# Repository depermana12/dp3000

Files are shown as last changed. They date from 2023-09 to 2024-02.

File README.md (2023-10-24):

# DP3000 Macropad
dp3000 macropad

dp3000 is a simple yet elegant macropad, integrated ATmega32u4 chip. I created this dev board named dp3000, the first and second letters are my initials and the three digit numbers are just random numbers like i love u 3000.

DP3000 Macropad
# Features
+ 2x4 (8 keys)
+ dual rotary encoder
+ oled display (support 128x32 or 128x64)
+ hot-swap socket (support mx style or kailh choc low profile)
+ mx style or low profile choc v1, v2* switch
    * *for choc v2 u need to file the center hole in the pcb, don't file pass the white circle line
+ RGB light underglow or RGB matrix
+ support QMK, VIA, VIAL
+ basic stacked acrylic case

# Gallery

dp3000 macropad dp3000 macropad dp3000 macropad
dp3000 macropad dp3000 macropad dp3000 macropad dp3000 macropad 
dp3000 macropad dp3000 macropad

# Getting started

dp3000 have 2 different types of firmware, QMK and VIA. Each firwmare have 2 version.
I recommend using VIA, it's user friendly, and easy to customize.

* rev1 version support `rgb_matrix`
* rev2 version support `rgblight` underglow
* (unofficial) rev3 version support both `rgb_matrix` and `rgblight` (hardware modification needed!)

1. choose your preferred firmware
2. flash the firmware
3. customize your keymap using VIA
4. profit?

# Default keymap


both firmware QMK and VIA come with above default keymap. However, it is important to note that the purpose of this board is primarily to serve as a customizable and programmable for macros.

so, the keymap configuration is intended to be personalized according to the user's specific needs and preferences. 
feel free to assign different keycodes or commands to each key, tailoring the macropad to your own workflow and requirements.

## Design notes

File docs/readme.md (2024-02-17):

# Introduction dp3000

dp3000 macropad  didesain full feature dan compact, tidak terlalu banyak switch

sekaligus jadi dev board

untuk nyoba fitur hardware dan firmware. Itu kenapa dp3000 didesain punya beberapa opsi

opsi lighting underglow atau rgbmatrix

opsi hot-swap socket

opsi ukuran modul oled

opsi firmware via, vial

## Embedded ATmega32u4

Dilihat lebih detil, dp3000 tidak memakai shield promicro... tapi ic promicro dipasang langsung di pcb dp3000

jadi lebih slim dan seksi

minimalis, elegan

alias manfaatin promicro yang port micro usbnya copot (type c pride)

biar ga mubazir

sayang 70rban

## Dev board

Untuk yang suka ngoprek firmware, atau lagi sambil belajar C, ini macropad cocok banget.

source code qmk terlampir

compiled .hex yang tinggal flash jg ada

firmware rev1 dan rev 2 sudah merged dengan repo qmk dan via

jadi sudah auto-detect untuk digunakkan langsung lewat web https://usevia.app

pcb juga mendukung untuk dimodif, hotswap socket bisa diganti ke varian choc socket

Oled bisa diganti ke ukuran 128x64

`rgb_matrix` bisa digabung `rgblight` underglow, dengan menyolder kabel jumper (tutorialnya menyusul)

icsp header

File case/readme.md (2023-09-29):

# Case akrilik dp3000

case ini sudah siap dipotong laser, untuk beli dan jasa potong akrilik saya rekomendasikan di [tokopedia.com/3dinnova](https://www.tokopedia.com/3dinnova) total harga sekitar Rp 30.000 untuk 3mm bening

1. Gunakan file 3mm case full jika keseluruhan 6 lapis akrilik ingin menggunakan warna akrilik yang sama
2. Jika ingin lapis akrilik bawah dan atas menggunakan warna berbeda, gunakan file bottom 3mm.dxf dan top 3mm.dxf

    - rekomendasi akrilik bawah menggunakan warna bening satin dengan kode 000M, karena frosted warna ini cocok untuk diffused led underglow
    - akrilik atas gunakan warna yang tembus oled, bisa warna bening, atau clear black.

contoh dari 3mm case full



contoh bottom 3mm



contoh mid 3mm



contoh top 3mm



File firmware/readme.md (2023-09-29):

# Compiled firmware

The compiled firmware is ready to flash, and you can download it from [here](https://drive.google.com/drive/folders/1hYmq0JSfdpY_xRYRoUmOEOPrWqblNjE2?usp=drive_link).

# Raw Firmware

* Rev. 1 Support RGB matrix
* Rev. 2 Support RGB light (underglow)

Make example for this keyboard (after setting up your build environment):

    make dp3000/rev1:default
    make dp3000/rev2:default
    make dp3000/rev1:via
    make dp3000/rev2:via

Flashing example for this keyboard:

    make dp3000/rev1:default:flash
    make dp3000/rev2:default:flash
    make dp3000/rev1:via:flash
    make dp3000/rev2:via:flash

See the [build environment setup](https://docs.qmk.fm/#/getting_started_build_tools) and the [make instructions](https://docs.qmk.fm/#/getting_started_make_guide) for more information. Brand new to QMK? Start with our [Complete Newbs Guide](https://docs.qmk.fm/#/newbs).

## Bootloader

Enter the bootloader in 3 ways:

* Bootmagic reset: Hold down the key at (0,0) in the matrix (left rotary encoder push switch) and plug in the keyboard
* Physical reset button: Briefly press reset button twice, located in front of the first rotary encoder (left rotary encoder)
* Keycode in layout: Press the key mapped to QK_BOOT if it is available

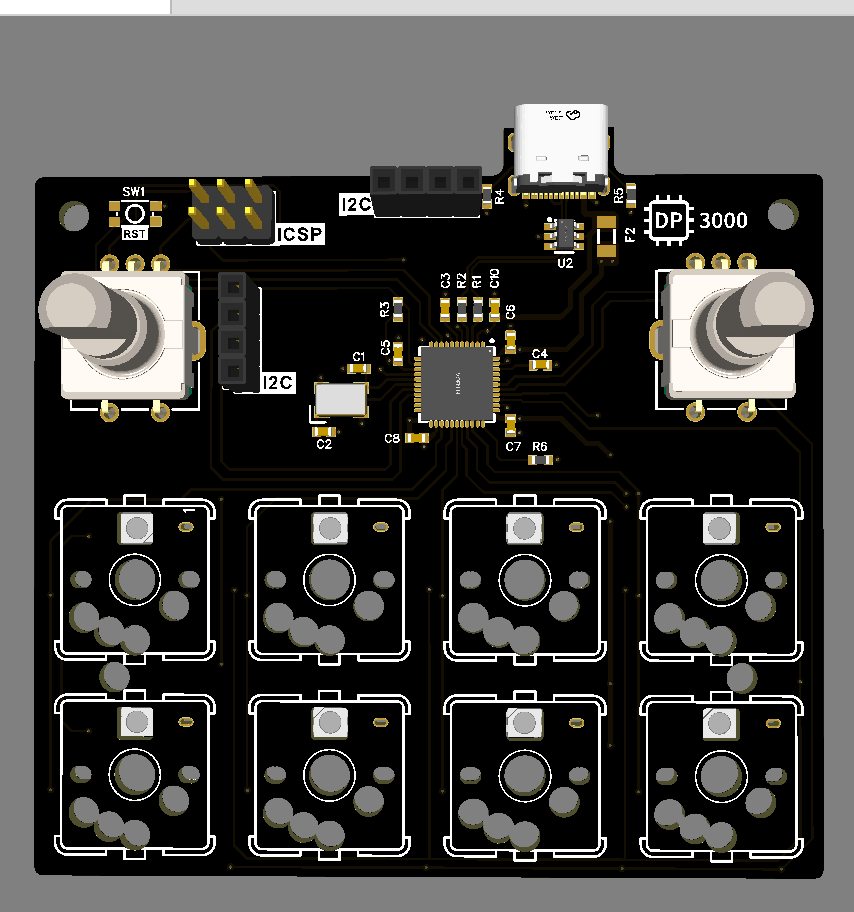
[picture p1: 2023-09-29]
gerber/front.png

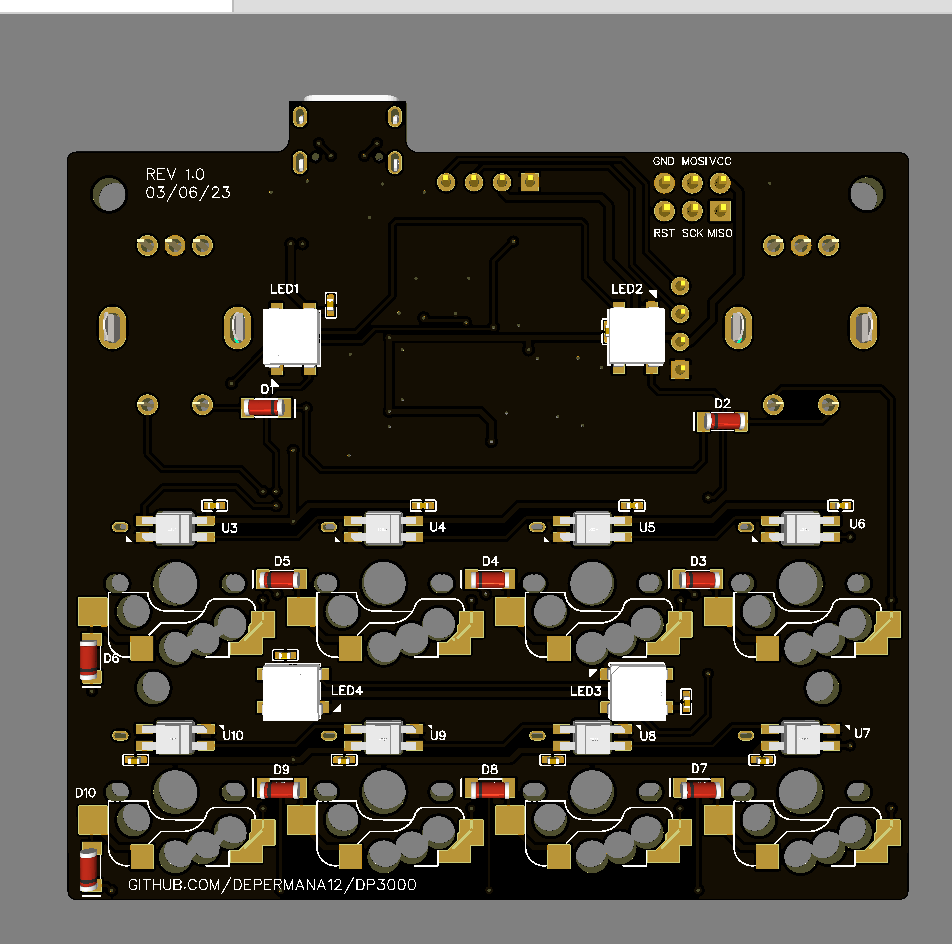
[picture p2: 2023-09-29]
gerber/back.png

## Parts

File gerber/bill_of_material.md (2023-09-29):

|ID |Part name |Origin |Package |Qty|
|---|---|---|---|---|
|1  |DISPLAY-OLED-128X32  |1,2 |I2C |2  |
|2  |22pF |C1,C2 |C0603 |2  |
|3  |1uF |C3 |C0603 |1  |
|4  |0.1uF |C4 |C0603 |1  |
|5  |0.1u |C5,C6,C7,C8 |C0603 |4  |
|6  |10uF |C10 |C0603 |1  |
|7  |0.1u |C11,C12,C13,C14,C15,C16,C17,C18,C19,C20,C21,C22|C0402 |12 |
|8  |1N4148(SMD) |D1,D2,D3,D4,D5,D6,D7,D8,D9,D10 |1N4148 SOD 123 |10 |
|9  |500mA ptc fuse |F2 |PTC-1206 |1  |
|10 |Header-Male-2.54_2x3 |J1 |2.54 pitch |1  |
|11 |5050-WS2812B |LED1,LED2,LED3,LED4 |WS2812B 5050 |4  |
|12 |5.1k |R1,R2,R4,R5 |R0603 |4  |
|13 |10k |R3,R6 |R0603 |2  |
|14 |16MHz |R7 |CRYSTAL-SMD_4P-L5.0-W3.2 |1  |
|15 |TS-1185A-020E |SW1 |SW-SMD_4P-L3.5-W3.0-LS4.6-TL |1  |
|16 |PEC11R-4015F-S0024 |SW2,SW35 |SW-TH_PEC11R-4XXXF-SXXXX |2  |
|17 |KAILH MX & CHOC |SW12,SW13,SW14,SW15,SW16,SW17,SW18,SW19 |SWITCH SOCKET MX & CHOC |8  |
|18 |ATMEGA32U4-MU |U1 |QFN-44 |1  |
|19 |SRV05 |U2 |SOT-23-6 |1  |
|20 |SK6812 MINI-E |U3,U4,U5,U6,U7,U8,U9,U10 |SK6812 MINI-E |8  |
|21 |KH-TYPE-C-16P |USB1 |USB TYPE C 16P |1  |

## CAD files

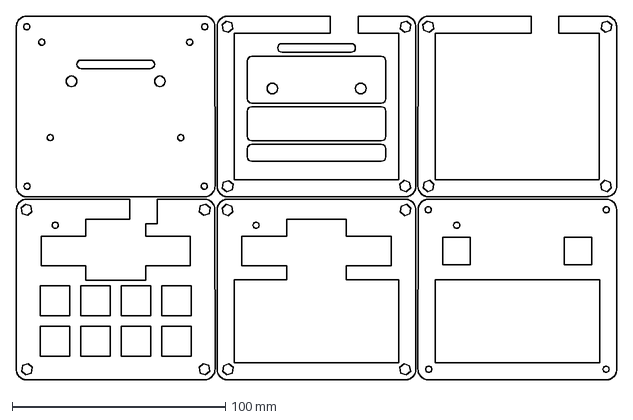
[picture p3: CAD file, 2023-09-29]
case/3mm case full.dxf
281.7 x 170.7 mm

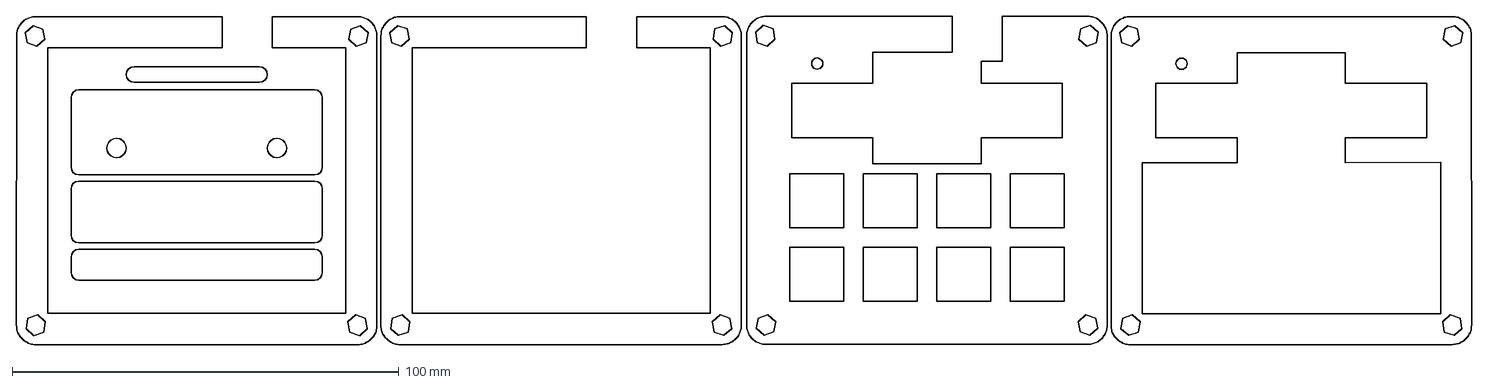
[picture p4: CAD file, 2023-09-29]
case/mid 3mm.dxf
376.2 x 84.9 mm

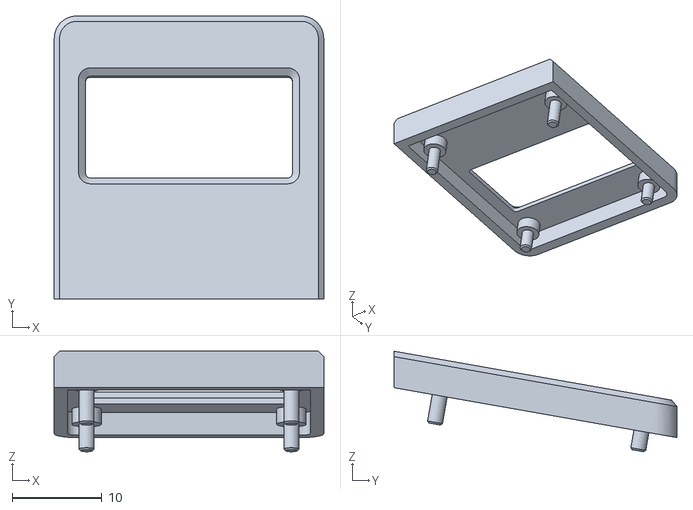
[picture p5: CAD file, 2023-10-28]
case/oled_case/oled_case_front.stl
30.0 x 31.5 x 11.2

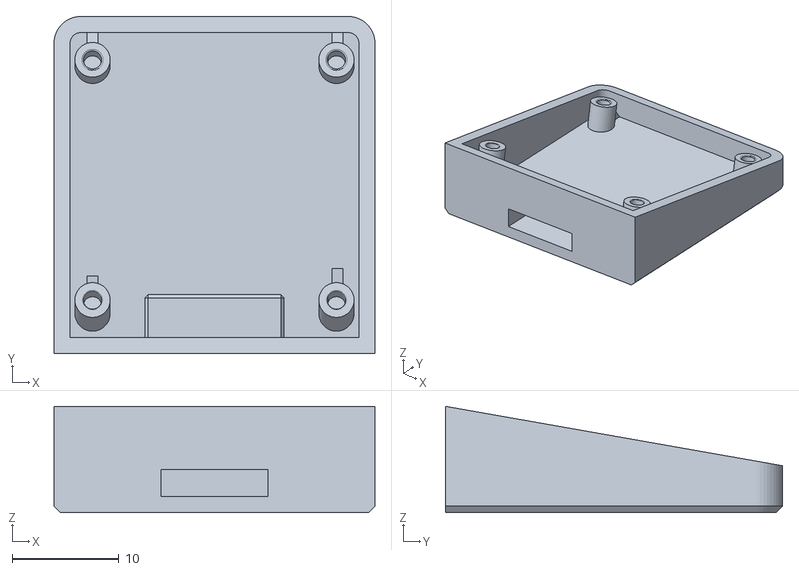
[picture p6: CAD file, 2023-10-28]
case/oled_case/oled_case_back.stl
30.0 x 31.5 x 9.94

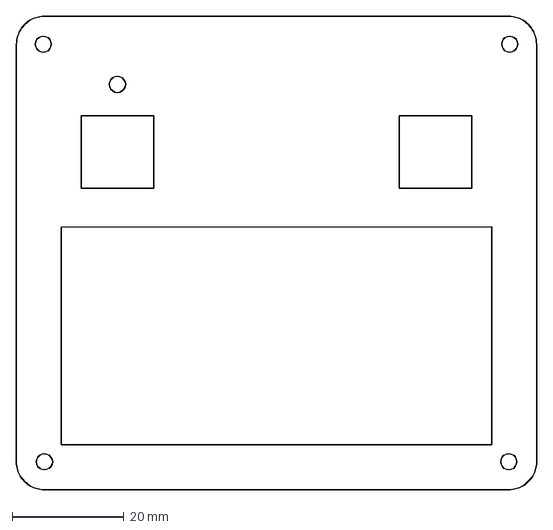
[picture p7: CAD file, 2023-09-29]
case/top 3mm.dxf
93.2 x 84.8 mm

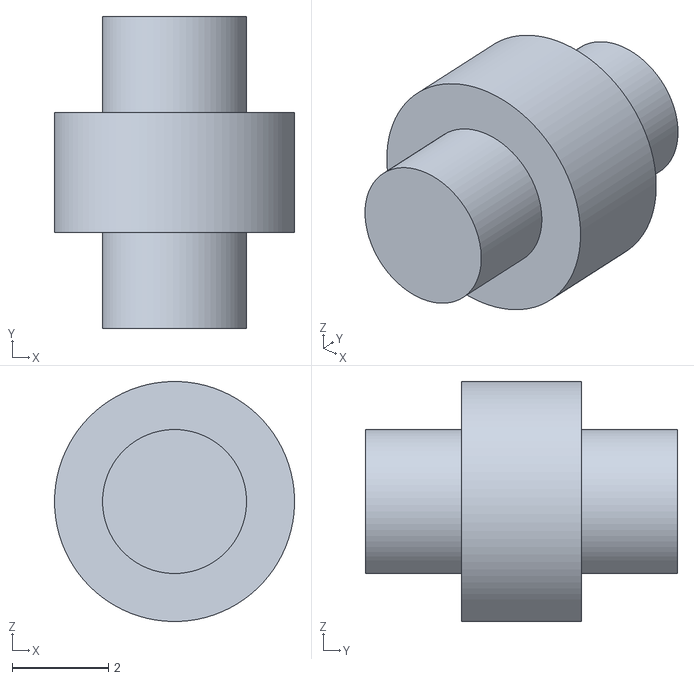
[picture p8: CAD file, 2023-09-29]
case/Mounting_standoff.stl
5.00 x 6.50 x 5.00

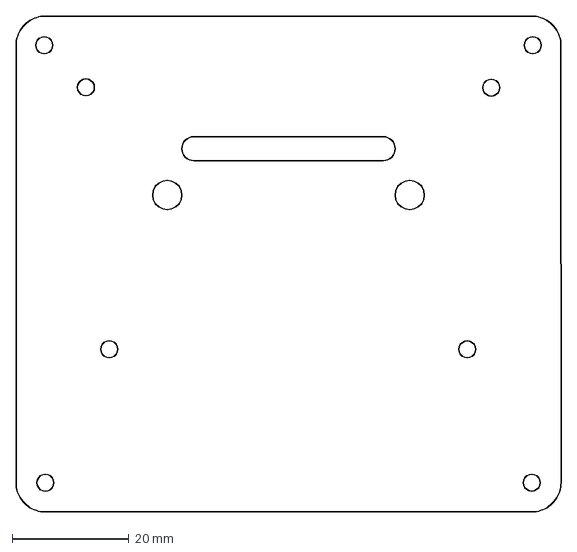
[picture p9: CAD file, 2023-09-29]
case/bottom 3mm.dxf
93.2 x 84.8 mm

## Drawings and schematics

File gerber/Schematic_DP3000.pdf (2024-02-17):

## USB INTERFACE

ICSP | MICROCONTROLLER

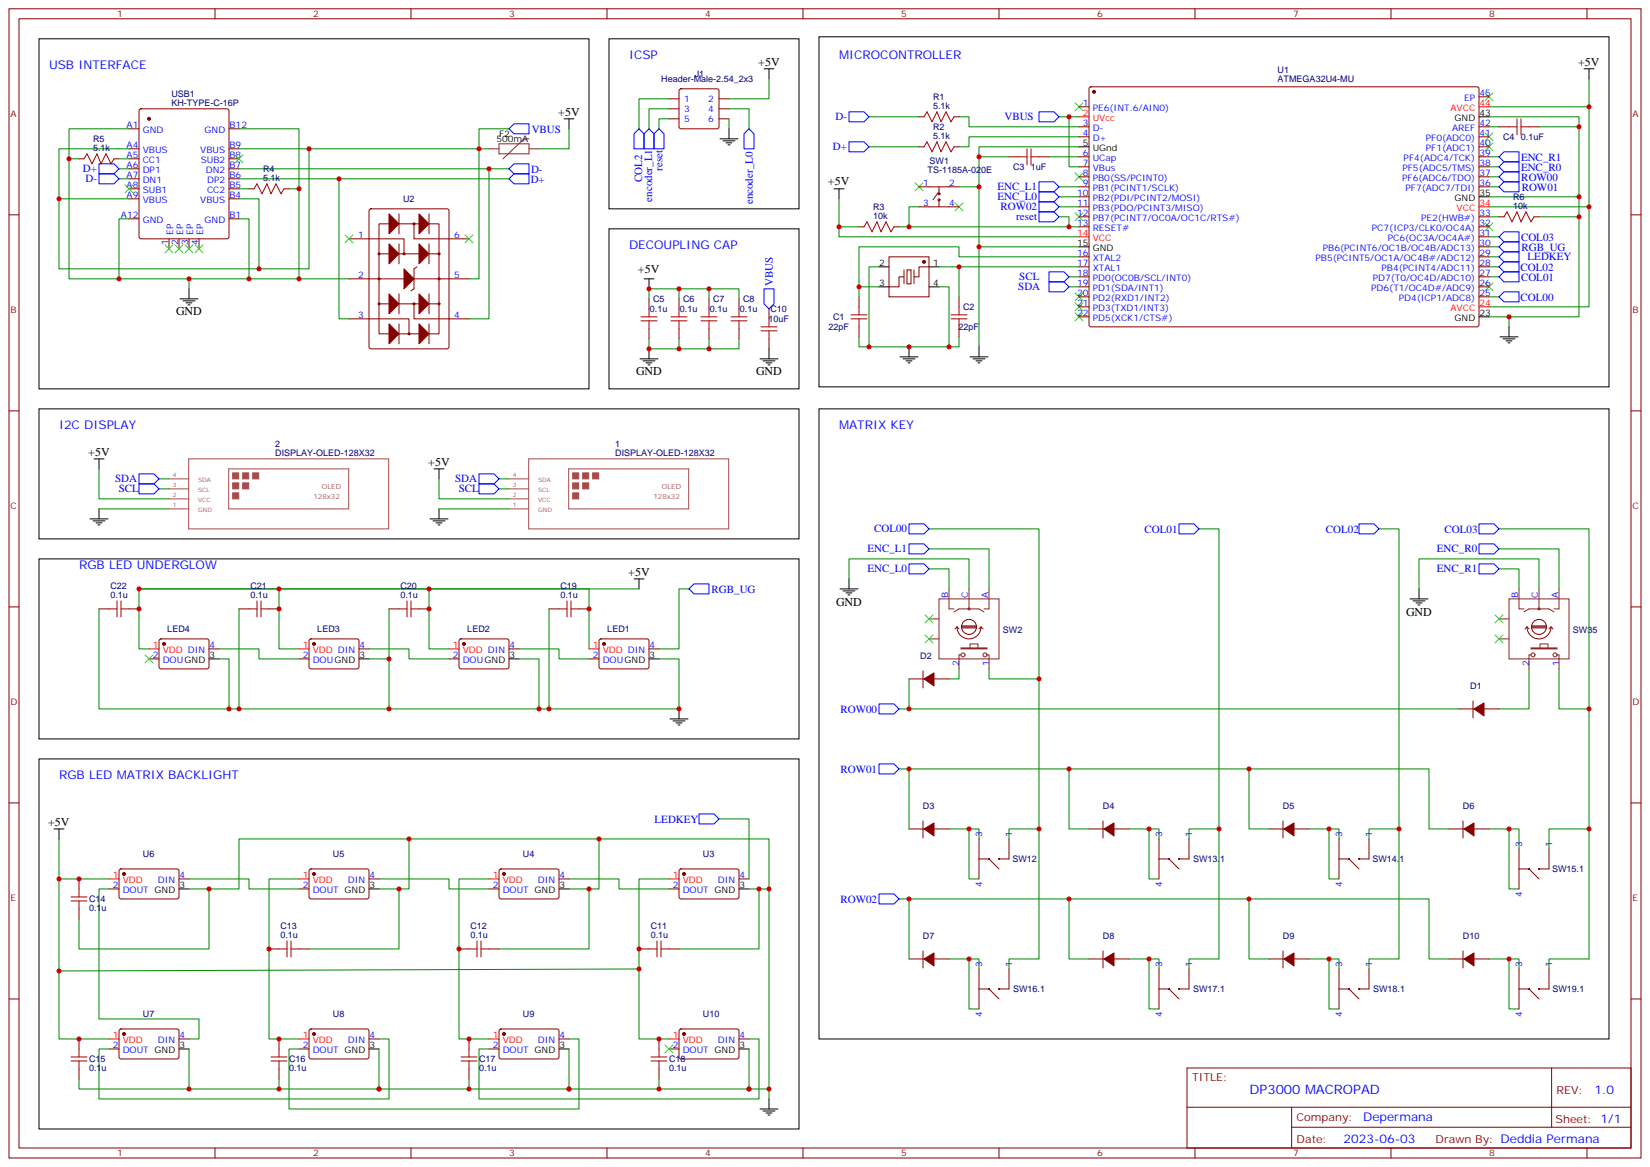
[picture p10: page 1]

RGB LED MATRIX BACKLIGHT

Drawn By: Deddia Permana

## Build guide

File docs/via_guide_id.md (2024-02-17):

# Panduan menggunakan VIA
Normal QMK firmware untuk mapping keymap membutuhkan modifikasi kode keymap.c di dalam build environment atau qmk configurator yang dicompile untuk menghasilkan file hex yang akan diflash. Cara ini cukup sulit dan tidak efisien untuk untuk beberapa pengguna.

VIA menutup gap tersebut dengan memberikan kemudahan pengguna untuk mengubah keymap tanpa harus flash firmware. Gui untuk mengatur lighting mode, speed, dan brightness. Programming macros.

Via adalah fitur yang berdiri dengan pondasi qmk firmware

## via configurator
VIA punya dua tipe configurator, web app dan desktop app. Panduan ini menggunakan web app agar lebih sederhana. Untuk desktop app sama saja seperti web app. 

Pastikan terkoneksi internet, dan gunakan browser yang mendukung web hid seperti chrome, safari, opera, edge.

1. buka alamat [VIA configurator](https://usevia.app/)
2. klik authorize device, pilih dp3000 lalu klik connect
   
dp3000 macropad

1. Tampilan setelah terkoneksi

dp3000 macropad

4. Pada tampilan di atas, pengguna dapat mengubah langsung setiap key di setiap layer. Jangan lupa juga untuk menambahkan key untuk berpindah layer

## Mapping rotary encoder

pengguna dapat melakukan mapping fungsi rotary encoder di setiap layer berbeda.

1. klik lingkaran rotary encoder
2. masukan fungsi untuk searah jarum jam, berlawan jarum jam, dan tombol rotary.

daftar fungsi [keycode qmk](https://docs.qmk.fm/#/keycodes)

dp3000 macropad

## Setting layer switching

Imgur

Secara bawaan dp3000 macropad mendukung 4 layer, dimulai dari 0 sebagai base default layer

Setting pindah layer dapat dilakukan di via dengan mengatur keymap dengan `LAYERS` keycode yang disediakan diatas.

Agar sederhana, pengguna dapat menggunakan basic keycode:

1. ``MO(nomor_layer)`` Momentary Open berfungsi untuk mengaktifkan layer sementara, saat ditekan akan mengaktifkan layer, saat dilepas akan kembali ke layer sebelumnya
2. ``TO(nomor_layer)`` Turn On berfungsi untuk mengaktifkan layer

Fungsi lengkap dapat dilihat di [QMK docs layer switching](https://docs.qmk.fm/#/feature_layers?id=switching-and-toggling-layers)

dp3000 macropad

Sebagai contoh gambar diatas adalah default keymap dp3000, berikut penjelasan cara pindah layer:

-  di layer 0 terdapat keycode `` MO(1)`` pada tombol rotary encoder, jadi saat tombol ditekan dan ditahan akan mengaktifkan layer 1
-  saat ada di layer 1, terdapat keycode untuk mengaktifkan layer ``TO(0)``, ``TO(2)``, ``TO(3)``
-  jadi saat menahan tombol ``MO(1)`` akan mengaktifkan layer 1, kemudian menekan tombol ``TO(2)``, Anda telah mengaktifkan dan berada pada layer 2
-  Indikator layer dapat dilihat pada tampilan oled

pengguna bisa mengubah dan mengatur layer switching sesuai kebutuhan dan kreatifitas

## Control RGB lighting

dp3000 macropad

dp3000 punya dua opsi lighting

- rev1 mendukung rgb_matrix, pada menu via bernama `BACKLIGHT`
- rev2 mendukung rbglight, pada menu via bernama `UNDERGLOW`

Beberapa kontrol pengaturan led seperti:
- Brightness untuk mengatur tingkat  cahaya led
- Effect untuk mengubah mode led
- Effect speed untuk mengubah kecepatan pada beberapa mode led
- Color untuk statis satu warna

## Macro
Macro adalah program untuk menjalankan serangkaian perintah dengan sekali tekan key. Digunakan untuk mengotomatisasi perintah atau shortcut sehingga menghemat waktu dan key.

sebagai contoh pengguna dapat membuat perintah copy ctrl+c ke dalam salah satu tombol. Pengguna juga dapat membuat perintah untuk membuat output teks ke dalam salah satu tombol.

Via punya dua metode untuk memprogram macro

1. Macro recorder

Metode ini akan merekam kombinasi tombol yang ditekan oleh pengguna

dp3000 macropad

2. Manual macro entry

Pengguna dapat memasukan fungsi kode keycode qmk sesuai contoh pada via

dp3000 macropad

## Macro shortcut app

Pengguna dapat membuat makro untuk membuka aplikasi spesifik. Cara ini menggunakan shortcut key yang ditempelkan ke aplikasi, dan macro via menggunakan shortcut key tersebut untuk membuka aplikasi.

1. Pengguna harus membuat shortcut key aplikasi

https://github.com/depermana12/dp3000/assets/28618836/631b59ea-c8a3-4074-a2fc-ed78b944b77b

2. Pengguna membuat macro pada via menggunakan macro recorder, kemudian masukan shortcut key yang sudah dibinding dengan aplikasi

https://github.com/depermana12/dp3000/assets/28618836/0c5c954b-eac3-4e96-9dee-aa7475304d08

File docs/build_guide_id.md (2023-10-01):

# Merakit dp3000 macropad
## Daftar komponen


|Komponen |Jumlah| Keterangan
|---|---|---
PCB dp3000 |1   | sudah terpasang ic atmega32u4 dan komponen seperti di gambar
case dp300 | 1 | 6 layer akrilik 3mm, sudah termasuk 4 spacer dan 8 baut m3
oled 128x32 | 1 | pixel putih
knob 20mm | 2 | warna silver
kunci L | 1| ukuran 2mm
spacer pcb | 4 | custom resin spacer mounting  PCB ke case
rubber feet | 4 |

## Cara memasang case

Ada 6 lembar akrilik yang akan ditumpuk, urutan pertama dimulai dari kiri atas sesuai pada gambar. Langkah di bawah hanya demonstrasi saja, jangan lupa untuk melepas lapisan pelindung akrilik.



1. Pasang 4 buah mounting spacer pada PCB



2. Pasang mounting PCB sesuai ke lubang base akrilik



3. Pasang lembar akrilik ke-2 dan ke-3, ratakan lembar akrilik kemudian masukan spacer kuningan



4. Pasang Oled display
5. pasang lembar akrilik ke-4 sampai terakhir, pasang 2 buah switch untuk mengunci sementara PCB, pasang 4 baut di atas dan di bawah



## Oled display

dp3000 macropad

dp3000 secara bawaan mendukung display oled berukuran 128x32. Pengguna dapat mengganti modul oled bawaan ke oled ukuran 128x64, perubahan yang diperlukan :

1. Pastikan modul oled 128x64 punya pinout yang sama, GND, VCC, SCL/SCK, SDA
2. penyolderan pin header female tipe bulat pada pcb dp3000, dan menggunakan pin bekas dioda atau yang seukuran pada pin oled, sehingga level ketinggiannya sama seperti oled bawaan
3. tambahkan kode `#define OLED_DISPLAY_128X64` pada `config.c` 
4. pada `dp3000.c` ganti `oled_write_raw_P(dp3000_logo, sizeof(dp3000_logo));` menjadi:

```
oled_set_cursor(0, (oled_max_lines() - 4) / 2);
oled_write_raw_P(dp3000_logo, sizeof(dp3000_logo));
 ```
4. compile dan flash

Atau silahkan langsung flash firmware dp3000 untuk oled 128x64, [download firmware khusus oled 128x64](https://drive.google.com/drive/folders/1Phvml8fCjT0DUVdHI3QOJoKWOjEaGGep?usp=drive_link)

Ada tambahan beberapa animasi untuk oled_128x64 seperti contoh bongo cat dll.

dp3000
# Flashing firmware

## Tipe revisi firmware dp3000
dp3000 punya 2 tipe revisi firmware, yang membedakan hanya pada lighting
- rev1 mendukung `rgb_matrix` backlight
- rev2 mendukung `rgblight` underglow
  
## Cara masuk mode bootloader
dp3000 menggunakan bootloader Caterina. Untuk masuk bootloader ada 3 cara:

1. tombol reset fisik  di depan rotary encoder sebelah kiri, tekan 2 kali
2. tekan dan tahan tombol rotary encoder sebelah kanan, lalu tekan tombol rotary encoder sebelah kiri
3. dalam keaadan kabel type c tidak terpasang, tekan dan tahan tombol rotary encoder sebelah kiri, lalu pasang kabel type c. Setelah terkoneksi, lepaskan tombol rotary.

Mode bootloader Caterina akan aktif kurang lebih selama 8 detik

## Cara flashing menggunakan qmk toolbox
Ada beberapa metode untuk flashing, menggunakan GUI dan CLI. Panduan ini hanya akan membahas penggunaan GUI QMK Toolbox.

1. download qmk toolbox dan firmware
   - download aplikasi [qmk toolbox versi terbaru](https://github.com/qmk/qmk_toolbox/releases)
   - download [firmware dp3000 macropad](https://drive.google.com/drive/folders/1hYmq0JSfdpY_xRYRoUmOEOPrWqblNjE2?usp=drive_link)

2. buka qmk_toolbox.exe, install driver
3. open untuk mencari firmware yang akan diflash
4. ceklis auto-flash



5. masuk mode bootloader dengan salah satu cara diatas, qmk toolbox akan mendeteksi dan langsung melakukan flash, tunggu sampai flash complete



6. Selamat Anda sudah berhasil flashing firmware

> Setiap habis flashing firmware dari versi rgb matrix ke versi underglow atau sebaliknya, lepas dan pasang kembali kabel type c untuk menghilangkan efek lighting sebelumnya.

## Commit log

2023-10-21 added oled case
    [back_case.stl, front_case.stl]
2023-10-28 update oled case
    [back_case.stl, front_case.stl, oled_case_back.stl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]
2024-02-17 update schematic: fix typo and misaligned
